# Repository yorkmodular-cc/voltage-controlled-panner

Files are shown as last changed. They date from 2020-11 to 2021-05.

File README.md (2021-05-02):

# VCP: Voltage-controlled panner

Shield: [][cc-by-sa]

This work is licensed under a
[Creative Commons Attribution-ShareAlike 4.0 International License][cc-by-sa].

[][cc-by-sa]

[cc-by-sa]: http://creativecommons.org/licenses/by-sa/4.0/
[cc-by-sa-image]: https://licensebuttons.net/l/by-sa/4.0/88x31.png
[cc-by-sa-shield]: https://img.shields.io/badge/License-CC%20BY--SA%204.0-lightgrey.svg

The VCP is a panning module that will take a mono input and split it to a pair of channels, hereafter referred to as 'left' and 'right'. The left/right mix can be controlled either by hand, using the CV pot on the front panel, or via a voltage source in which case the CV pot acts like an attenuator for the incoming signal.

It has other uses too - by only using the right output (R), the module can be made to behave like a somewhat crude, but rather effective, VCA.

## Construction

Construction uses through-hole components _except_ for components F1 and F2, which are 1206 SMD pads. These are used by the current limiting resistors or polyfuses. Polyfuses are recommended (fuses rated up to 100mA should be more than adequate) but ferrites or 22ohm resistors could be substituted instead. Should an over-current situation happen, the SMD components are far easier to replace than their through-hole counterparts.

There are no particular gotchas with regard construction apart from the use of matched transistors in the differential pairs (Q1,Q2 and Q3,Q4). Any small signal NPN transistor (2N2222, 2N3904 etc.) can be used here.

Ideally, the resistors in the legs of the differential pairs (R2/R3 and R12/R13) should be matched, but this is less essential than matched transistors - I find that 1% resistors are good enough; anything tighter is overkill.

The recommended op-amp configuration is TL072/082 for U1 and NE5532 or similar for U2 - this isn't set in stone though, and any dual op-amp which is pin-compatible with the TL0x2 series will work. If you don't have any NE5532s then a pair of TL082s or similar will work quite happily. My own preference is for a pair of TL082s.

## Calibration
There are a couple of ways in which the module can be calibrated, depending on whether or not you have an oscilloscope.

*If you have a scope*:

- Connect a signal of known amplitude to the input and turn the level pot fully clockwise. A VCO is good for this - for best results, use a square-wave output.
- Connect the output of the right-hand channel and move the CV pot to roughly 12 o'clock
- Adjust the trimmer potentiometer until the amplitude of the signal is roughly half that of the input signal eg. if the input signal is 5V p-p, adjust the trimmer until it is 2.5V p-p.

*If you don't have a scope*:

You'll have to calibrate by ear - follow the procedure above, but instead of connecting the RH channel to a scope, connect it to your speaker or mixer. Adjust the trimmer until the output sounds right.

Clearly this is far less accurate than using a scope, but it does the job.

# Usage
The 'accepted' control voltage range is 0-12V - negative voltages will be rejected. If you're using a through-zero oscillator as a modulation source you may find it necessary to add a DC offset such that the CV is always greater than 0V. 

A CV of 0V corresponds to a 'fully left' signal whilst a CV of 12V corresponds to 'fully right' - values within this range correspond to various proportions of the signal going to the left and right outputs. If you've got matched transistors and have calibrated the module correctly, an input CV of 6V should correspond to a 50:50 mix to the left and right channels.

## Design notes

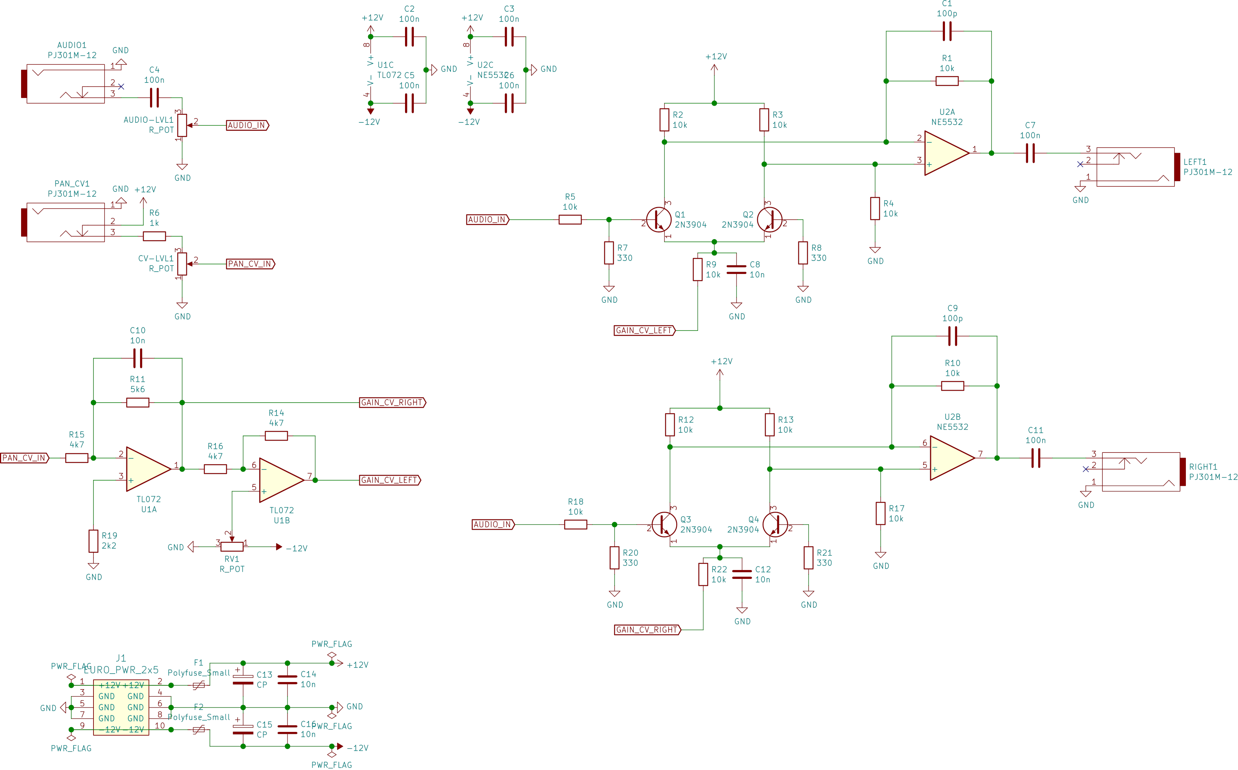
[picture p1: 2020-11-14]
vcpanner.png

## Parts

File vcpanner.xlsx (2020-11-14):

Ref | Value | Description | Notes
AUDIO1 | PJ301M-12 |  | Signal input
AUDIO-LVL1 | A100k | Alpha 9mm potentiometer or equivalent | Log/audio taper
C1 | 100p | Ceramic capacitor | 47p or 82p will also work
C2 | 100n | Ceramic capacitor | Decoupling capacitor
C3 | 100n | Ceramic capacitor | Decoupling capacitor
C4 | 100n | Ceramic capacitor
C5 | 100n | Ceramic capacitor | Decoupling capacitor
C6 | 100n | Ceramic capacitor | Decoupling capacitor
C7 | 100n | Ceramic capacitor
C8 | 10n | Ceramic capacitor
C9 | 100p | Ceramic capacitor | 47p or 82p will also work
C10 | 10n | Ceramic capacitor
C11 | 100n | Ceramic capacitor
C12 | 10n | Ceramic capacitor
C13 | 10u | Polarized capacitor | 5mm diameter, 2 or 2.5mm lead pitch
C14 | 100n | Ceramic capacitor | Decoupling capacitor
C15 | 10u | Polarized capacitor | 5mm diameter, 2 or 2.5mm lead pitch
C16 | 100n | Ceramic capacitor | Decoupling capacitor
CV-LVL1 | R_POT | Alpha 9mm potentiometer or equivalent
F1 | Polyfuse_Small | Resettable fuse, polymeric positive temperature coefficient, small symbol | 1206 SMD - 22R resistor or ferrite also works
F2 | Polyfuse_Small | Resettable fuse, polymeric positive temperature coefficient, small symbol | 1206 SMD - 22R resistor or ferrite also works
J1 | EURO_PWR_2x5 | 2x5 IDC connector
LEFT1 | PJ301M-12 | 3.5mm mono jack | Left channel output
PAN_CV1 | PJ301M-12 | 3.5mm mono jack | Pan CV input
Q1 | 2N3904 | 0.2A Ic, 40V Vce, Small Signal NPN Transistor, TO-92 | Match with Q2
Q2 | 2N3904 | 0.2A Ic, 40V Vce, Small Signal NPN Transistor, TO-92 | Match with Q1
Q3 | 2N3904 | 0.2A Ic, 40V Vce, Small Signal NPN Transistor, TO-92 | Match with Q4
Q4 | 2N3904 | 0.2A Ic, 40V Vce, Small Signal NPN Transistor, TO-92 | Match with Q3
R1 | 10k | Resistor
R2 | 10k | Resistor | Match with R3
R3 | 10k | Resistor | Match with R2
R4 | 10k | Resistor
R5 | 10k | Resistor
R6 | 1k | Resistor
R7 | 330R | Resistor
R8 | 330R | Resistor
R9 | 10k | Resistor
R10 | 10k | Resistor
R11 | 5k6 | Resistor
R12 | 10k | Resistor | Match with R13
R13 | 10k | Resistor | Match with R12
R14 | 4k7 | Resistor
R15 | 4k7 | Resistor
R16 | 4k7 | Resistor
R17 | 10k | Resistor
R18 | 10k | Resistor
R19 | 2k2 | Resistor
R20 | 330R | Resistor
R21 | 330R | Resistor
R22 | 10k | Resistor
RIGHT1 | PJ301M-12 | 3.5mm mono jack | Right channel output
RV1 | B100k | Alpha 9mm potentiometer or equivalent | Linear taper
U1 | TL072 | Dual Low-Noise JFET-Input Operational Amplifiers, DIP-8/SOIC-8 | Any pin-compatible dual op-amp will work
U2 | NE5532 | Dual Low-Noise Operational Amplifiers, DIP-8/SOIC-8 | Any pin-compatible dual op-amp will work

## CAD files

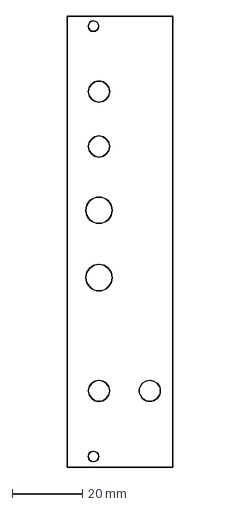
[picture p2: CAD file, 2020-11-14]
vcpanner-flat.dxf
30.1 x 128.4 mm

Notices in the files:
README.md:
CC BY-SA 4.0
